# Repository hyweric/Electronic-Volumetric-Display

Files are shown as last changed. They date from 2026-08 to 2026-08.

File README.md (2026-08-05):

# Electronic Volumetric Display

This is a hand-held persistence-of-vision display built around the STM32WB55 microcontroller. It works by spinning a vertical RGB LED array fast enough to create three-dimensional images in space. The device will include a sensor suite for orientation sensing or viewer positioning and control.

The end goal is to have a custom slicer convert 3D models into LED frames that the STM32WB55 can display at the correct motor positions. Bluetooth will be used for control and content transfer, while USB-C is used only for battery charging and external power. The platform can display general volumetric graphics or operate as an electronic hourglass by linking its animations to a timer.

The Altium project uses shared symbols and footprints from the Altium Generic Components library. Clone that repository beside this project.

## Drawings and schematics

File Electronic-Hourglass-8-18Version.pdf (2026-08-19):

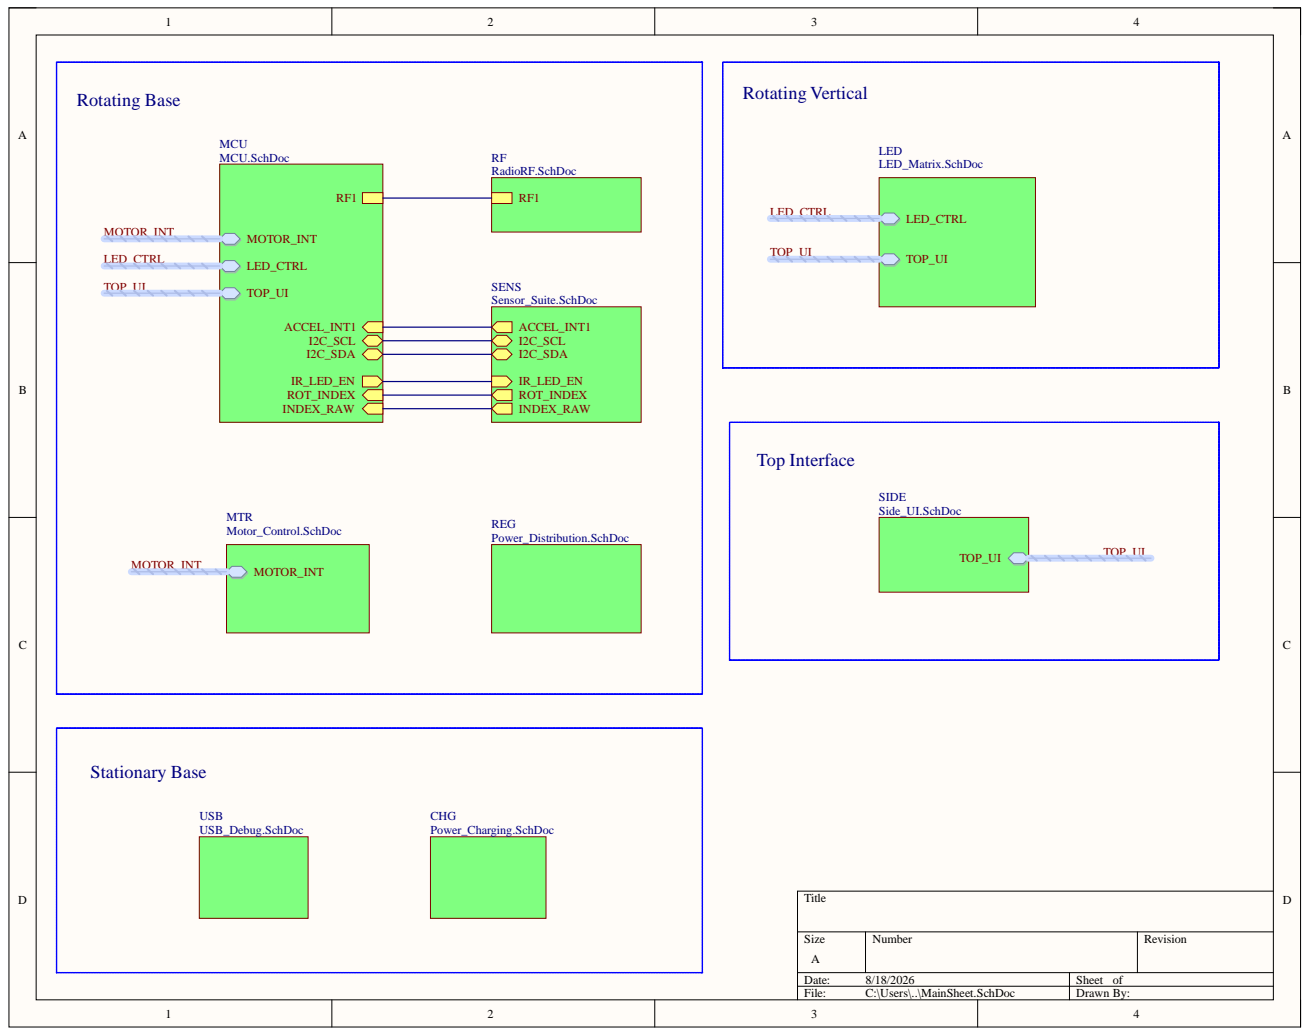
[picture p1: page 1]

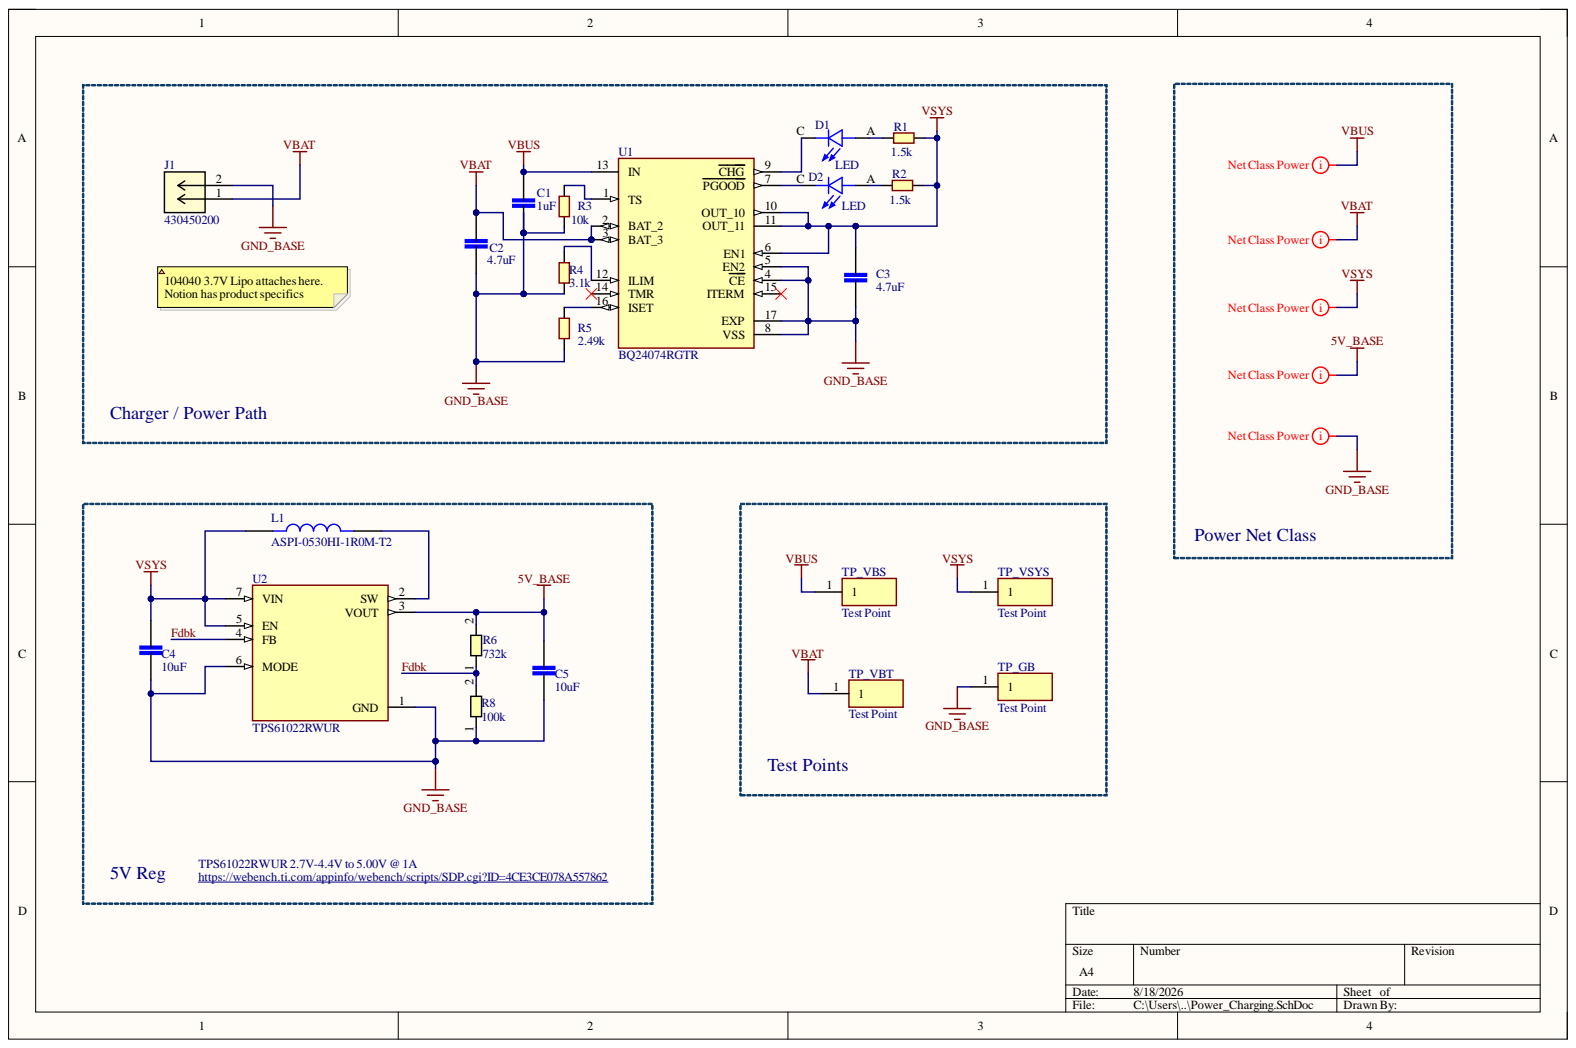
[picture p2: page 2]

104040 3.7V Lipo attaches here.
Notion has product specifics

https://webench.ti.com/appinfo/webench/scripts/SDP.cgi?ID=4CE3CE078A557862

Size A4 | Number | Revision

Date: 8/18/2026 | Sheet of
File: C:\Users\..\Power_Charging.SchDoc | Drawn By:

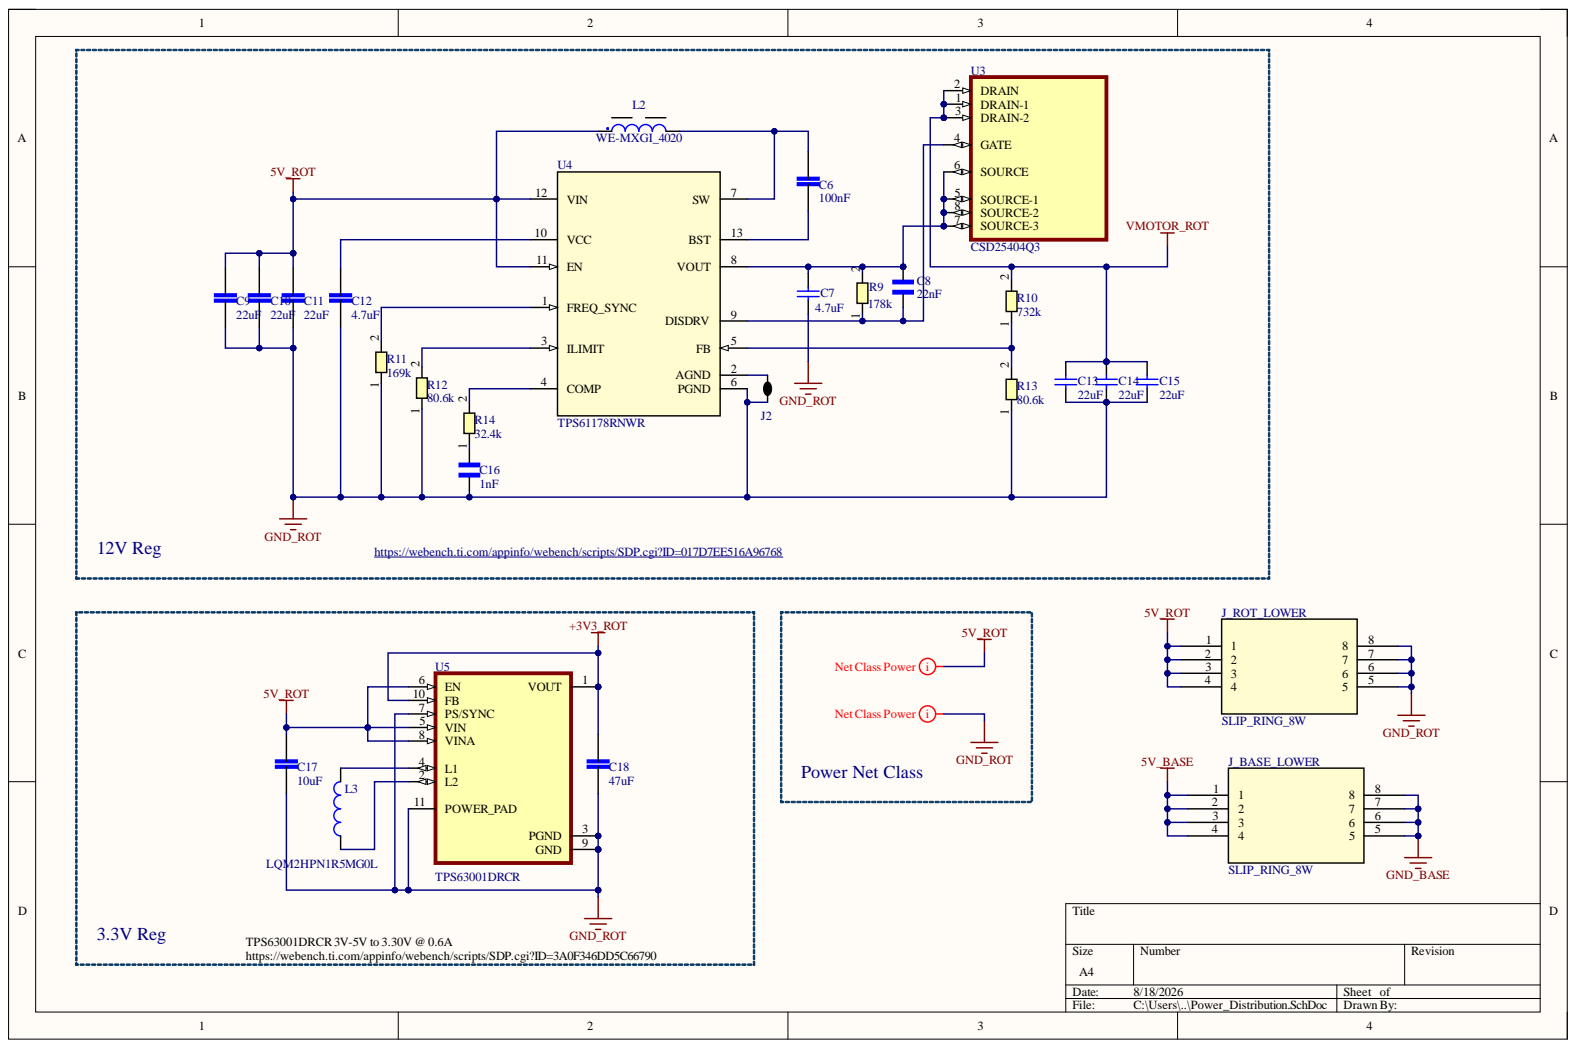
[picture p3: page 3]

https://webench.ti.com/appinfo/webench/scripts/SDP.cgi?ID=017D7EE516A96768

PS/SYNC 7

VINA 8

L3 | | POWER_PAD 11

TPS63001DRCR3V-5V to 3.30V @ 0.6A
https://webench.ti.com/appinfo/webench/scripts/SDP.cgi?ID=3A0F346DD5C66790

Size A4 | Number | Revision

Date: 8/18/2026 | Sheet of
File: C:\Users\..\Power_Distribution.SchDoc | Drawn By:

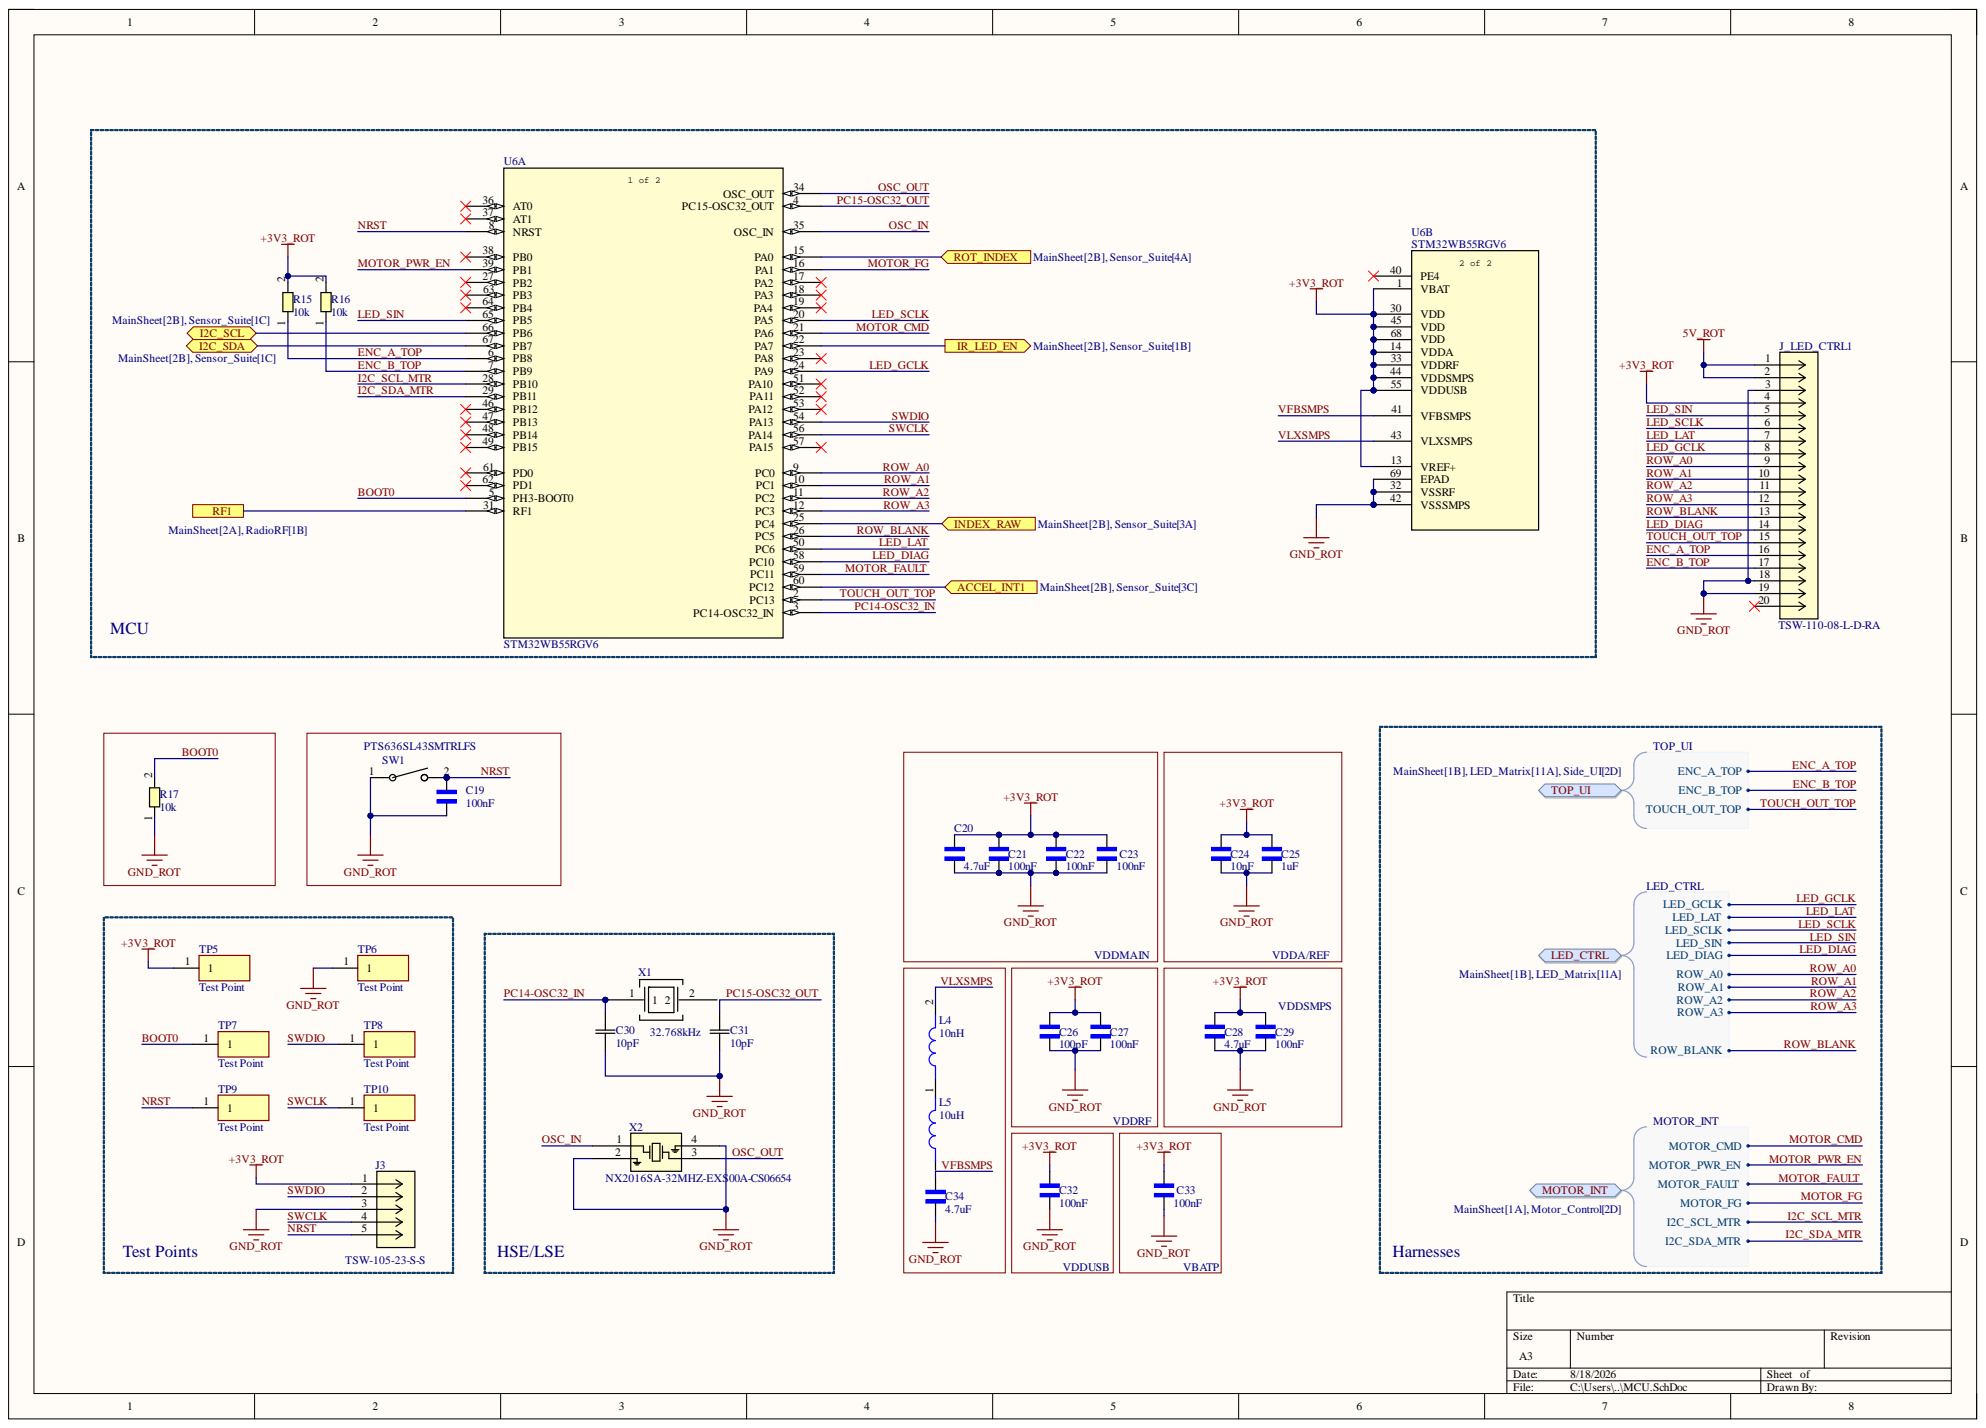
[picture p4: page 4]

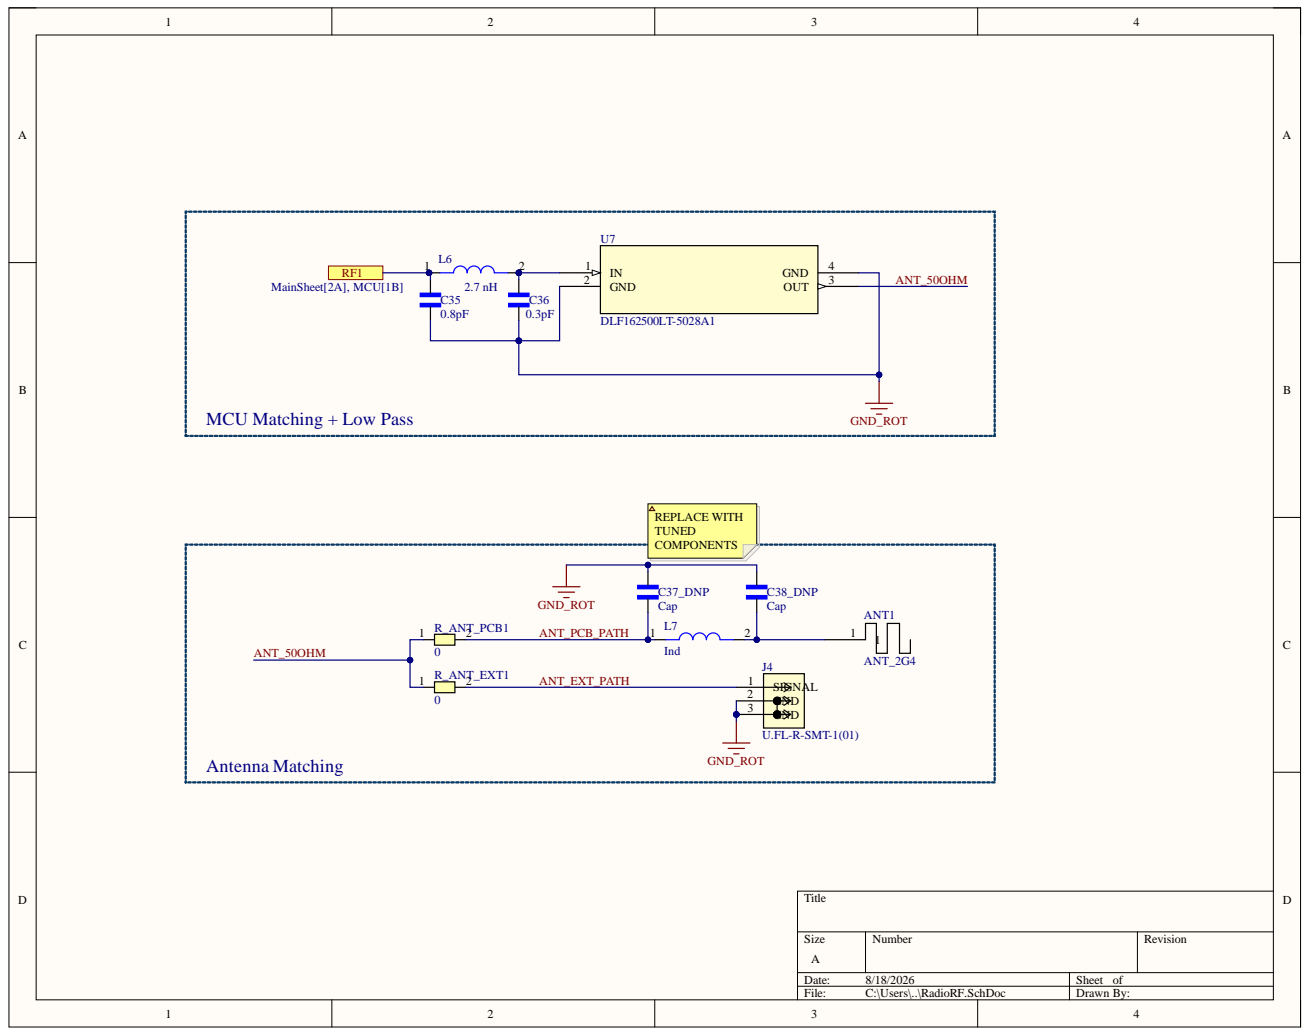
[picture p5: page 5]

MCU Matching + Low Pass

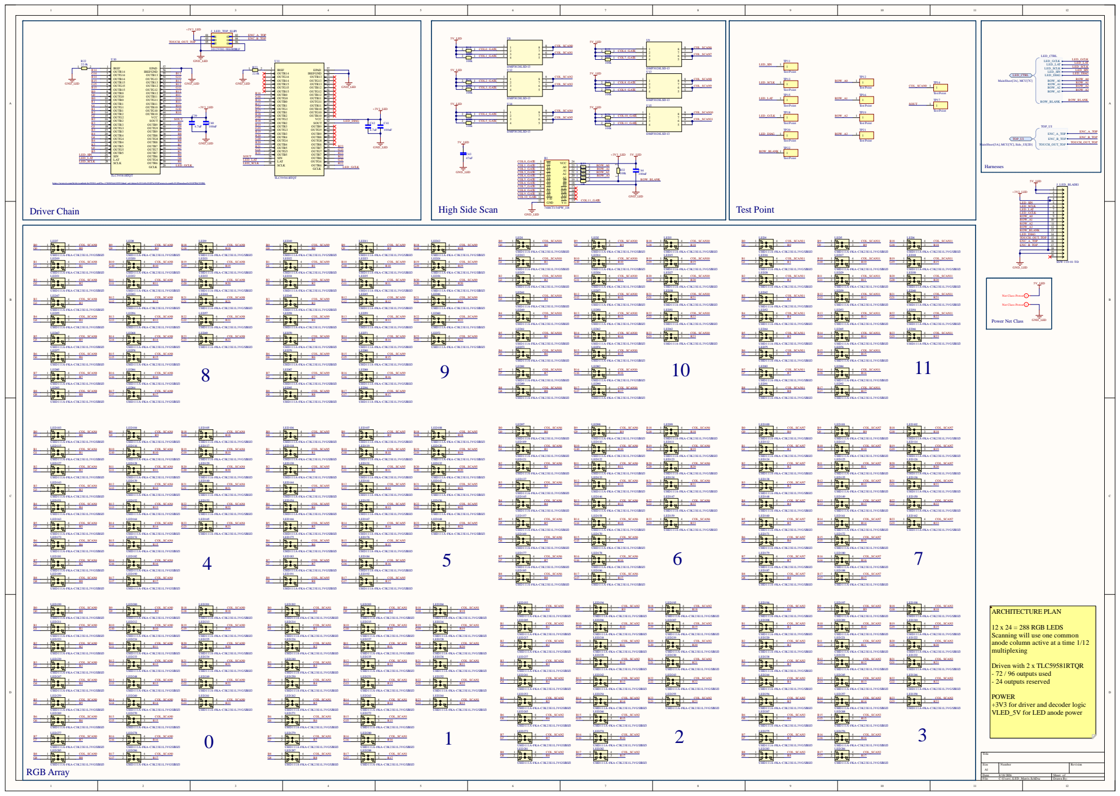
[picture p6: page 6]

https://www.ti.com/lit/ds/symlink/tlc59581.pdf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

12 x 24 = 288 RGB LEDS
Scanning will use one common

anode column active at a time 1/12

+3V3 for driver and decoder logic
VLED_5V for LED anode power

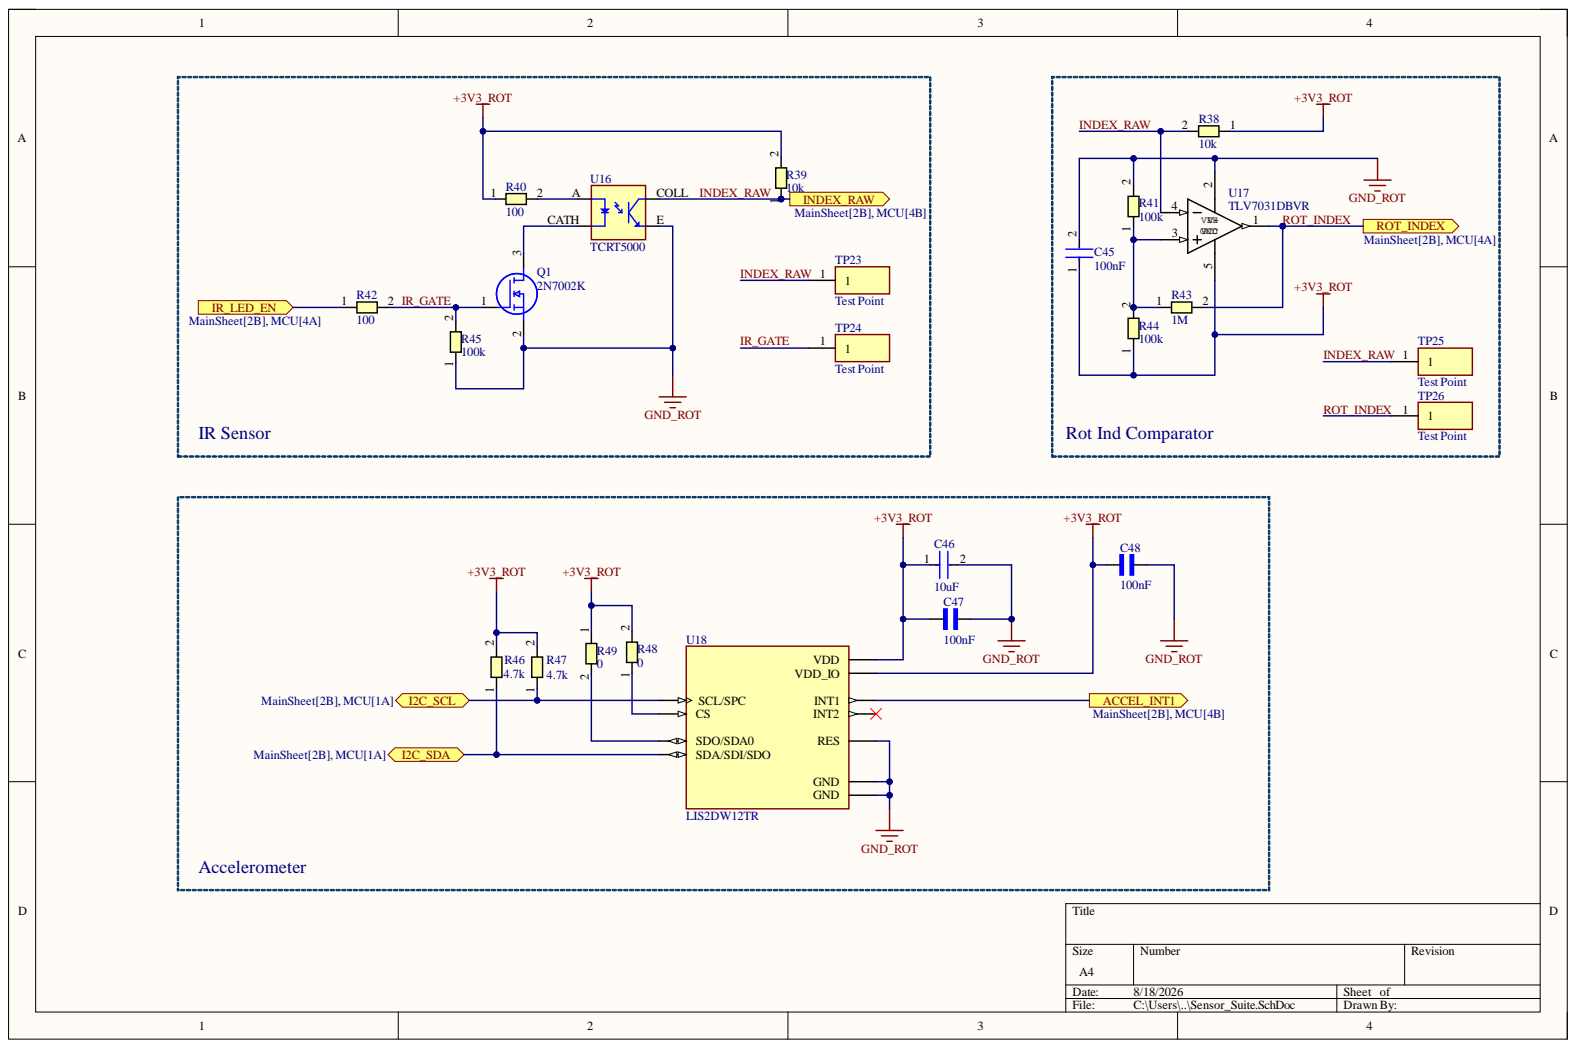
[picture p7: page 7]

Size A4 | Number | Revision

Date: 8/18/2026 | Sheet of
File: C:\Users\..\Sensor_Suite.SchDoc | Drawn By:

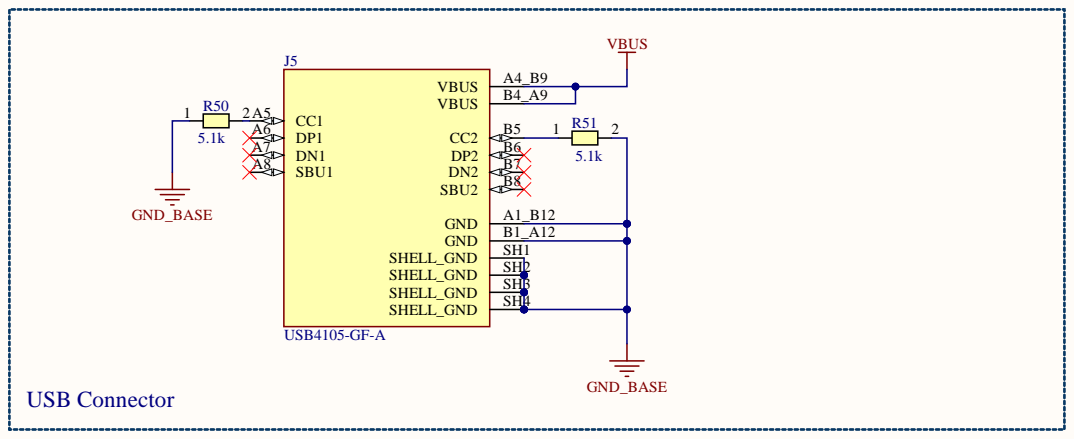
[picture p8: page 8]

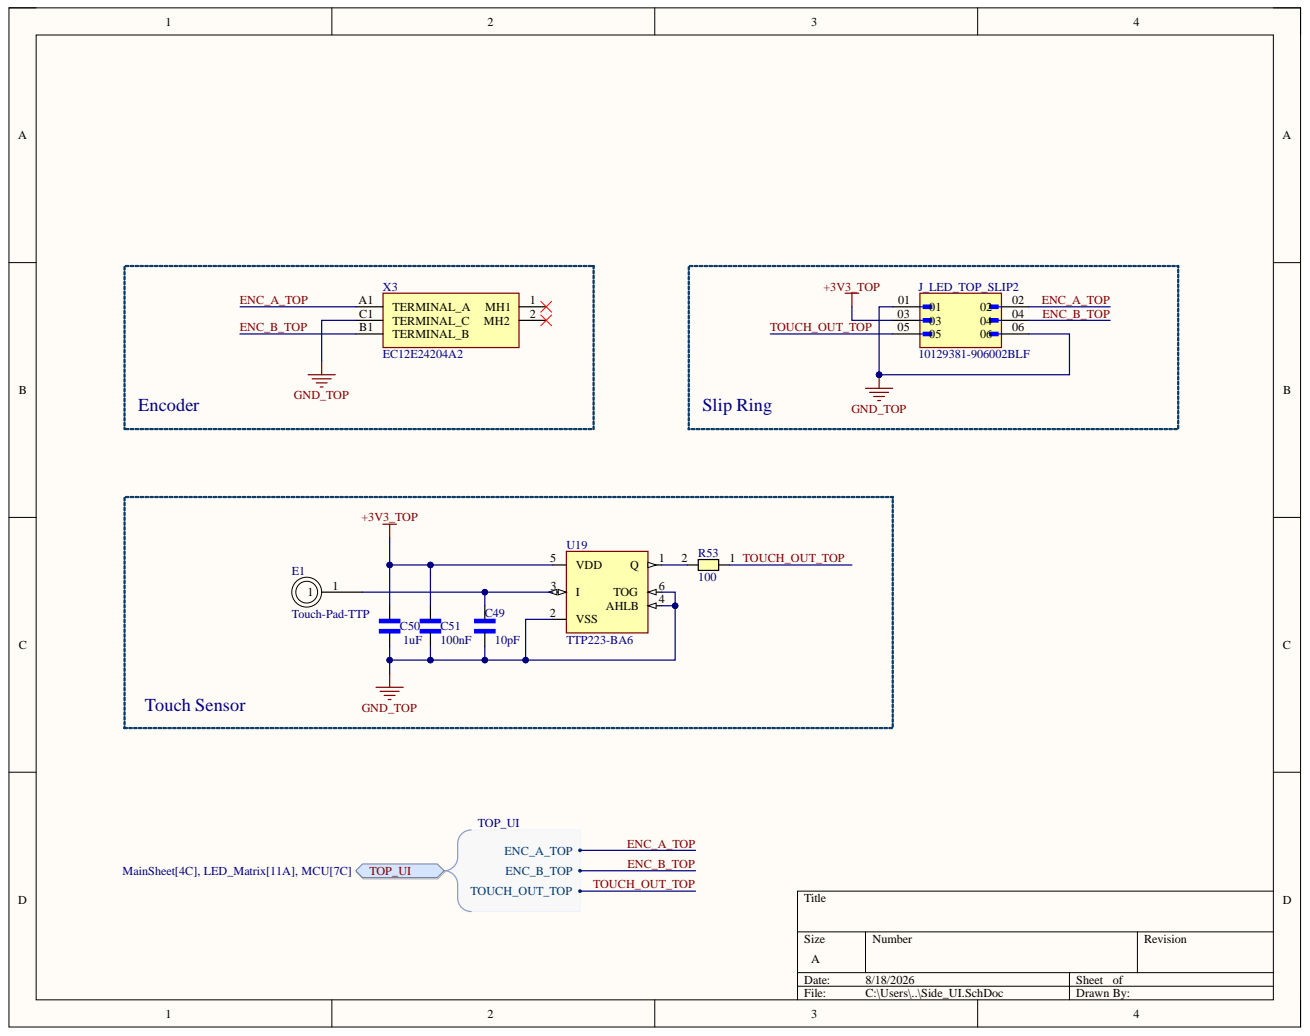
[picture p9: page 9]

VSS 2

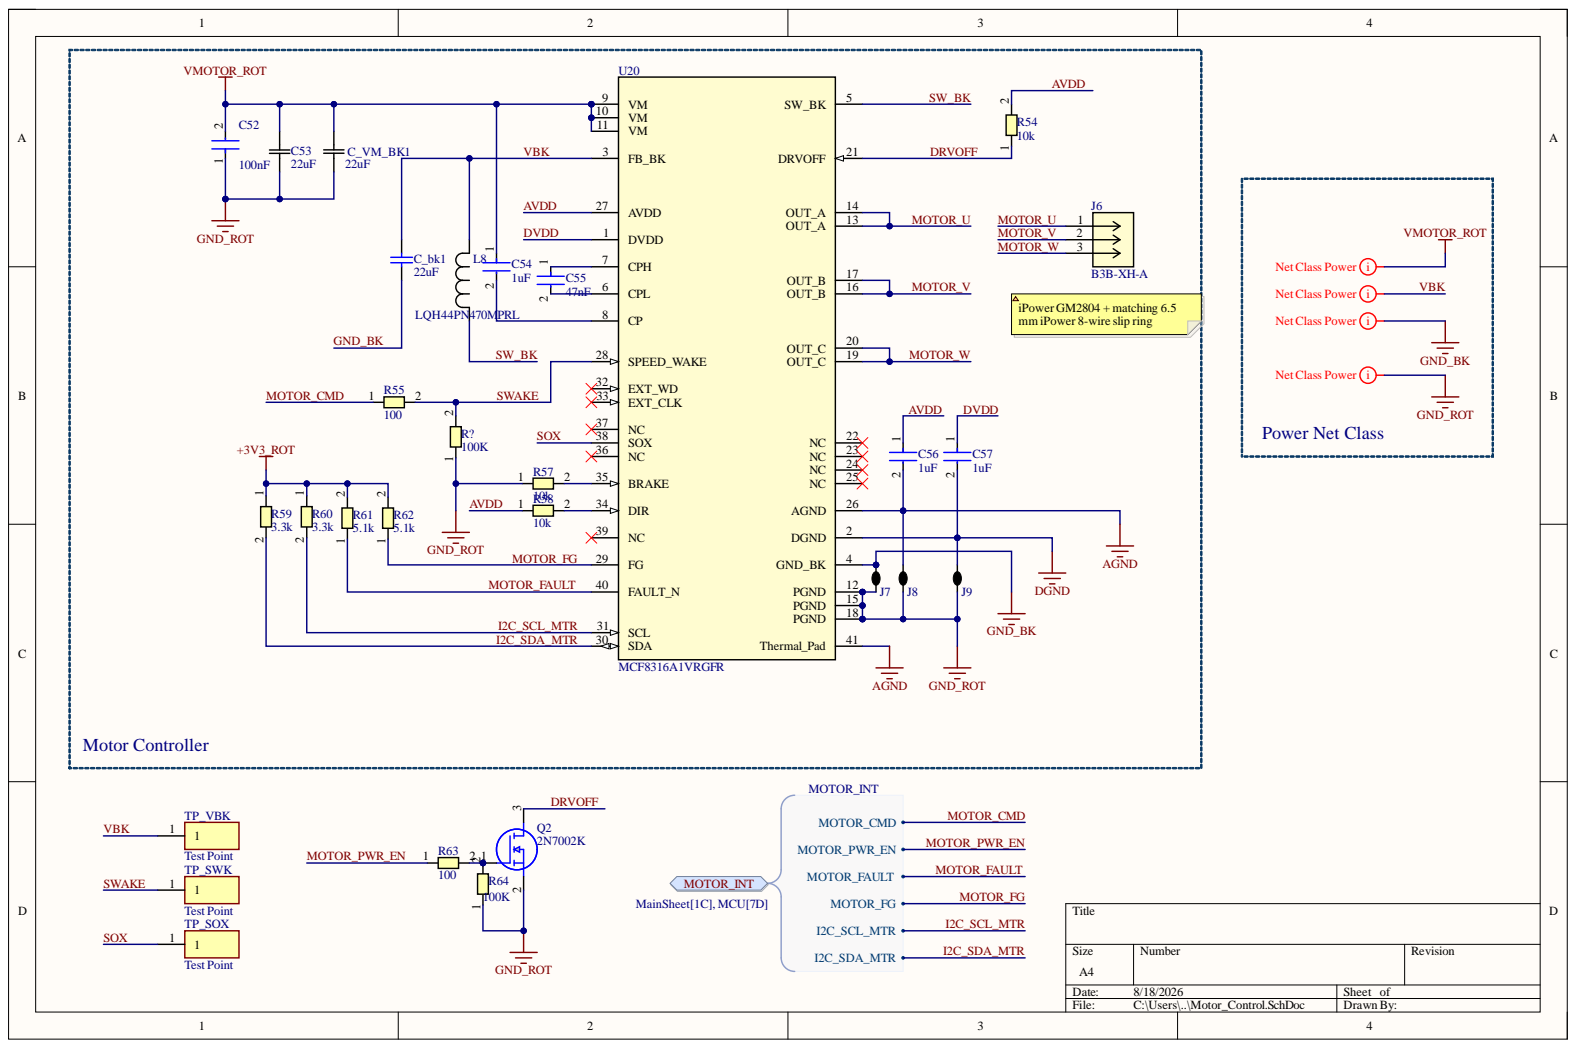
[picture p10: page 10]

CPL 6 | B3B-XH-A iPower GM2804 + matching 6.5

mm iPower 8-wire slip ring

SW_BK | | SPEED_WAKE 28

SWAKE | | EXT_WD 32

Size A4 | Number | Revision

Date: 8/18/2026 | Sheet of
File: C:\Users\..\Motor_Control.SchDoc | Drawn By:

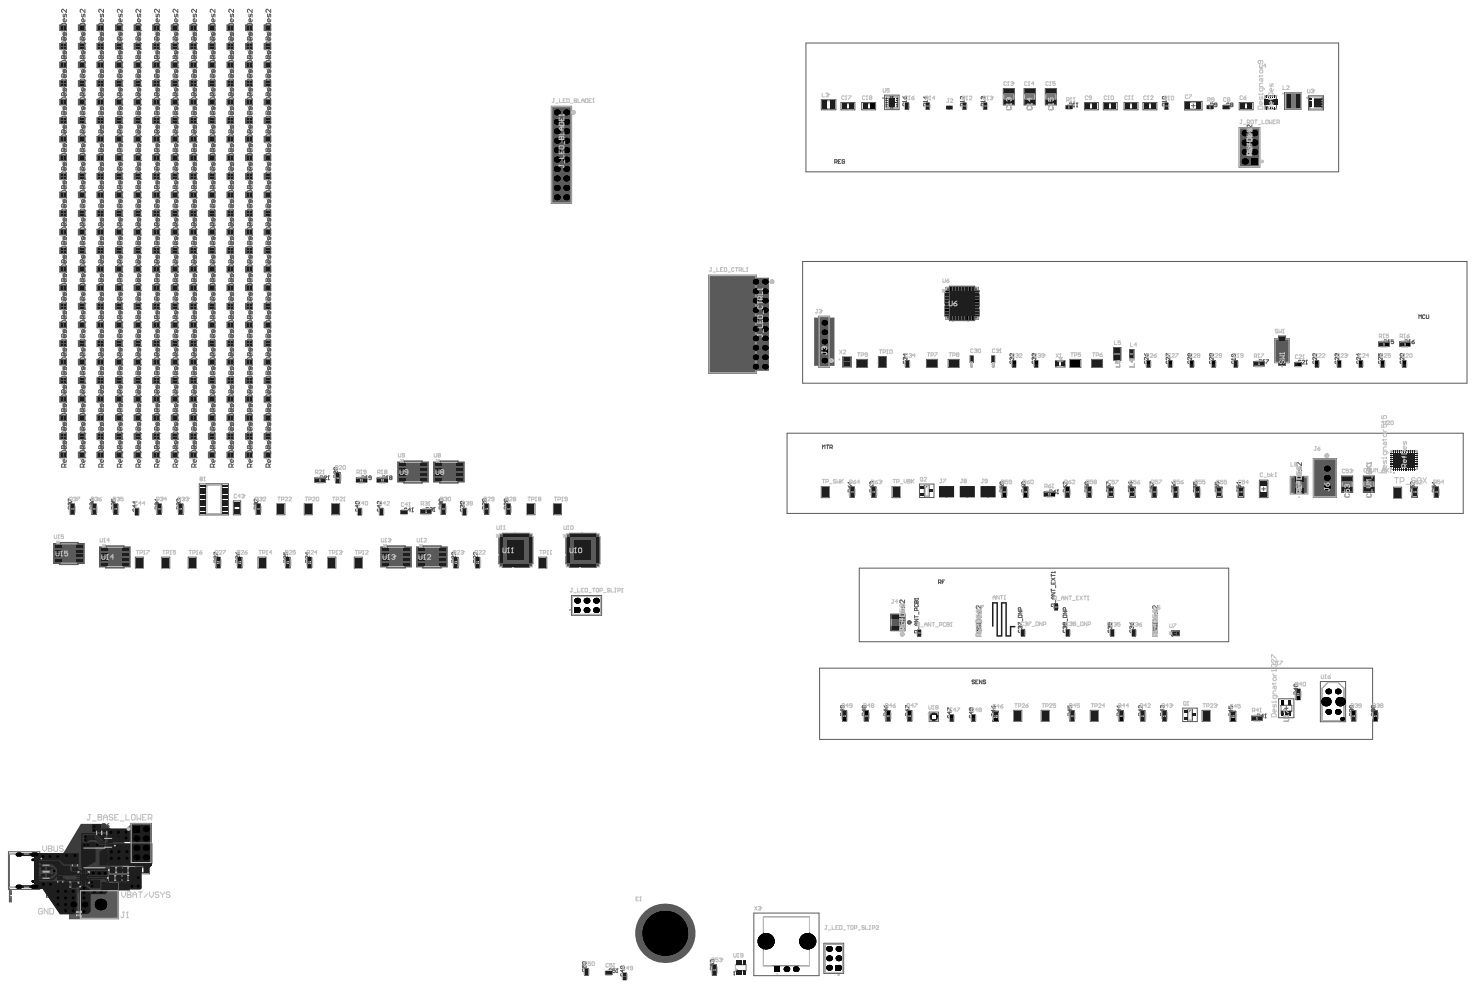
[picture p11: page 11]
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

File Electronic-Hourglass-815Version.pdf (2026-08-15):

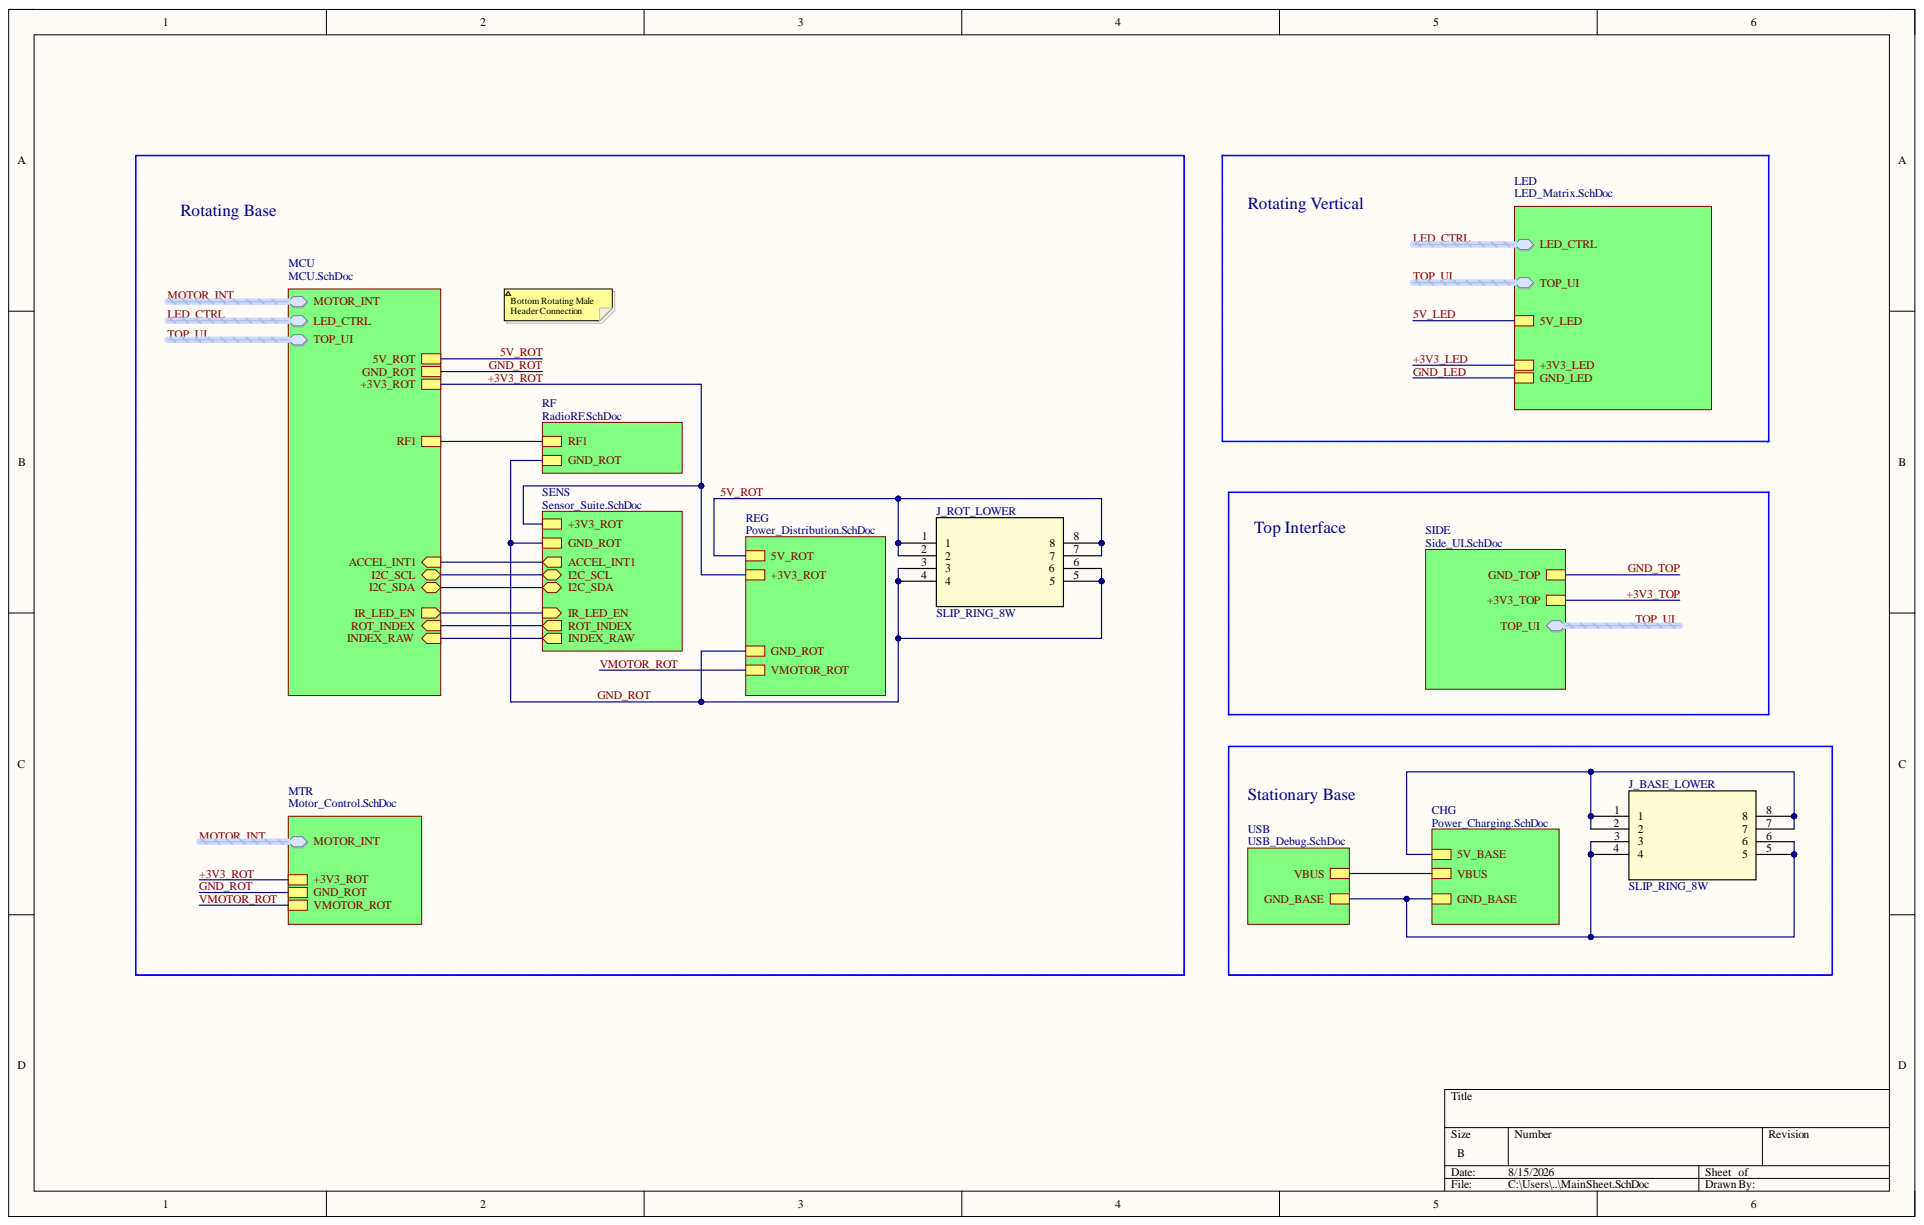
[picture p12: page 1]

SENS Sensor_Suite.SchDoc

REG Power_Distribution.SchDoc | J_ROT_LOWER

Size B | Number | Revision

Date: 8/15/2026 | Sheet of
File: C:\Users\..\MainSheet.SchDoc | Drawn By:


BAT_3 3 | | | VSYS

ILIM 12

104040 3.7V Lipo attaches here.
Notion has product specifics

https://www.ti.com/lit/ds/symlink/bq24074.pdf

https://webench.ti.com/appinfo/webench/scripts/SDP.cgi?ID=4CE3CE078A557862

Size A4 | Number | Revision

Date: 8/15/2026 | Sheet of
File: C:\Users\..\Power_Charging.SchDoc | Drawn By:


https://webench.ti.com/appinfo/webench/scripts/SDP.cgi?ID=017D7EE516A96768

FB 10
PS/SYNC 7
VIN 5 VINA 8

L1 4
L2 2

L3 | POWER_PAD 11

https://webench.ti.com/appinfo/webench/scripts/SDP.cgi?ID=3A0F346DD5C66790
TPS63001DRCR3V-5V to 3.30V @ 0.6A

Size A4 | Number | Revision

Date: 8/15/2026 | Sheet of
File: C:\Users\..\Power_Distribution.SchDoc | Drawn By:



MCU Matching + Low Pass


https://www.ti.com/lit/ds/symlink/tlc59581.pdf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

12 x 24 = 288 RGB LEDS
Scanning will use one common

anode column active at a time 1/12

+3V3 for driver and decoder logic
VLED_5V for LED anode power


GND VCC

+3V3_ROT

Size A4 | Number | Revision

Date: 8/15/2026 | Sheet of
File: C:\Users\..\Sensor_Suite.SchDoc | Drawn By:



VSS 2


CPL 6 | B3B-XH-A iPower GM2804 + matching 6.5

mm iPower 8-wire slip ring

SW_BK | | SPEED_WAKE 28

SWAKE | | EXT_WD 32

NC 39 | DGND

MOTOR_FG | FG 29 | GND_BK

Size A4 | Number | Revision

Date: 8/15/2026 | Sheet of
File: C:\Users\..\Motor_Control.SchDoc | Drawn By:

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

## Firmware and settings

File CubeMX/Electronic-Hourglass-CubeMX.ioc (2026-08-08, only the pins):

Mcu.UserName=STM32WB55RGVx
PA0.GPIO_Label=ROT_INDEX
PA0.Signal=S_TIM2_CH1
PA1.GPIO_Label=MOTOR_FG
PA1.Signal=S_TIM2_CH2
PA11.Signal=USB_DM
PA12.Signal=USB_DP
PA13.Signal=SYS_JTMS-SWDIO
PA14.Signal=SYS_JTCK-SWCLK
PA5.Signal=SPI1_SCK
PA6.GPIO_Label=MOTOR_CMD
PA6.Signal=S_TIM16_CH1
PA7.GPIO_Label=IR_LED_EN
PA7.Signal=S_TIM17_CH1
PA9.Signal=S_TIM1_CH2
PB0.GPIO_Label=VLED_EN
PB0.Signal=GPIO_Output
PB1.GPIO_Label=MOTOR_PWR_EN
PB1.Signal=GPIO_Output
PB10.GPIO_Label=I2C_SCL_MTR
PB10.Signal=I2C3_SCL
PB11.GPIO_Label=I2C_SDA_MTR
PB11.Signal=I2C3_SDA
PB5.Signal=SPI1_MOSI
PB6.GPIO_Label=I2C_SDA
PB6.Signal=I2C1_SCL
PB7.GPIO_Label=I2C_SCL
PB7.Signal=I2C1_SDA
PC0.GPIO_Label=ROW_A0
PC0.Signal=GPIO_Output
PC1.GPIO_Label=ROW_A1
PC1.Signal=GPIO_Output
PC10.GPIO_Label=LED_DIAG
PC10.Signal=GPIO_Input
PC11.GPIO_Label=MOTOR_FAULT
PC11.Signal=GPXTI11
PC12.GPIO_Label=ACCEL_INT1
PC12.Signal=GPXTI12
PC13.GPIO_Label=TOUCH_OUT_TOP
PC13.Signal=GPXTI13
PC14-OSC32_IN.Signal=RCC_OSC32_IN
PC15-OSC32_OUT.Signal=RCC_OSC32_OUT
PC2.GPIO_Label=ROW_A2
PC2.Signal=GPIO_Output
PC3.GPIO_Label=ROW_A3
PC3.Signal=GPIO_Output
PC4.GPIO_Label=INDEX_RAW
PC4.Signal=ADCx_IN13
PC5.GPIO_Label=ROW_BLANK
PC5.Signal=GPIO_Output
PC6.GPIO_Label=LED_LAT
PC6.Signal=GPIO_Output

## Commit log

2026-07-12 Create Altium hierarchical schematic
    [Electronic-Hourglass.PrjPcb, LED_Matrix.SchDoc, MCU.SchDoc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]
2026-07-13 Add power subsystem hierarchy and rail interfaces
    [Electronic-Hourglass.PrjPcb, MainSheet.SchDoc, Power.SchDoc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]
2026-07-20 Added Charging Circuit, work on regulation next
    [Electronic-Hourglass.PrjPcb, MCU.SchDoc, PcbLib1.PcbLib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]
2026-07-21 Buck-Boost and Regulation
    [Electronic-Hourglass.PrjPcb, MainSheet.SchDoc, PcbLib1.PcbLib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]
2026-07-21 Power Charging and Distribution Reorg
    [MainSheet.SchDoc, Power.SchDoc, Power_Charging.SchDoc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]
2026-07-24 STM32 Power, Decoupling, SMPS
    [Electronic-Hourglass.PrjPcb, MCU.SchDoc, MainSheet.SchDoc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]
2026-07-25 STM32WB RF matching schematic
    [MCU.SchDoc, MainSheet.SchDoc, PcbLib1.PcbLib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]
2026-07-25 Add STM32WB55 CubeMX configuration
2026-07-26 Fix Footprints
    [MCU.SchDoc, MainSheet.SchDoc, Power_Charging.SchDoc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]
2026-07-27 Complete LED matrix schematic and create README
    [LED_Matrix.SchDoc]
2026-07-27 Add untracked files
    [Electronic-Hourglass.PrjPcb, MCU.SchDoc, MainSheet.SchDoc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]
2026-07-28 Add 5V reg
    [Electronic-Hourglass.PrjPcb, LED_Matrix.SchDoc, MCU.SchDoc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]
2026-07-31 Sensor Suite implementation
    [LED_Matrix.SchDoc, MCU.SchDoc, MainSheet.SchDoc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]
2026-08-05 Architecture Reorg + Rot Index Comparator
    [LED_Matrix.SchDoc, MCU.SchDoc, MainSheet.SchDoc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]
2026-08-05 Remove obsolete sheets and update submodule architecture
    [Schlib1.SchLib, Sensor_Suite.SchDoc, Side_UI.SchDoc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]
2026-08-06 Motor Controller Draft
    [Electronic-Hourglass.PrjPcb, MCU.SchDoc, MainSheet.SchDoc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]
2026-08-07 Motor Reg
    [Motor_Control.SchDoc, PcbLib1.PcbLib, Power_Distribution.SchDoc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]
2026-08-09 All schematic sheets populated and antenna added
    [Electronic-Hourglass.PrjPcb, LED_Matrix.SchDoc, MCU.SchDoc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]
2026-08-09 harnesses and connector restructure checkpoint
    [Electronic-Hourglass.PrjPcb, LED_Matrix.SchDoc, MCU.SchDoc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]
2026-08-09 Schematic Glam Makeover
    [Electronic-Hourglass.PrjPcb, LED_Matrix.SchDoc, MCU.SchDoc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]
2026-08-12 Checklist A1-18 done
    [LED_Matrix.SchDoc, MCU.SchDoc, MainSheet.SchDoc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]
2026-08-14 Add rotating base PCB project and stackup
    [Rotating_Base.PrjPcb]
2026-08-14 Update schematics and add rotating base PCB
    [Electronic-Hourglass.PrjPcb, LED_Matrix.SchDoc, MCU.SchDoc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]
2026-08-14 Full Sheet Architecture decision checkpoint
    [Electronic-Hourglass.PrjPcb, FullSheet.PcbDoc, MCU.SchDoc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]
2026-08-15 PCB Layout Groups, LED script
    [Electronic-Hourglass.PrjPcb, FullSheet.PcbDoc, Power_Charging.SchDoc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]
2026-08-16 Buck Charging Progress
    [Electronic-Hourglass.PrjPcb, FullSheet.PcbDoc, LED_Matrix.SchDoc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]
2026-08-18 base PCB layout rough, schematic subject to change still
    [Electronic-Hourglass.PrjPcb, FullSheet.PcbDoc, PcbLib1.PcbLib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]
2026-08-19 Global Power Nets and other fixes
    [Electronic-Hourglass.PrjPcb, FullSheet.PcbDoc, LED_Matrix.SchDoc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]
2026-08-19 Minor designator and power fixes
    [Electronic-Hourglass.PrjPcb, LED_Matrix.SchDoc, MainSheet.SchDoc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]
2026-08-30 sense start checkpoint
    [FullSheet.PcbDoc, MCU.SchDoc, Motor_Control.SchDoc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]
2026-08-31 Preliminary MCU Routing
    [FullSheet.PcbDoc, MCU.SchDoc, Motor_Control.SchDoc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]
2026-09-06 led wiring in progress
    [Electronic-Hourglass.PrjPcb, FullSheet.PcbDoc, LED_Matrix.SchDoc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]
2026-09-07 led matrix setup
    [FullSheet.PcbDoc]
2026-09-07 mirrored led driver footprint mishap
    [FullSheet.PcbDoc, LED_Matrix.SchDoc, PcbLib1.PcbLib]
